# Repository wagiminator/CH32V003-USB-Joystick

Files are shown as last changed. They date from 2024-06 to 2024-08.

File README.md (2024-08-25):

# CH32V003 USB Joystick - Simple Joystick with USB Interface
The USB Joystick is a versatile device that combines the functionality of an analog joystick with the convenience of a USB interface. It is based on the affordable CH32V003 32-bit RISC-V microcontroller. One of the standout features of the USB Joystick is that it requires no driver installation, making it incredibly easy to use. The device acts as a USB Human Interface Device (HID), meaning that it can be recognized and utilized by most computers without the need for additional software. This makes the USB Joystick an ideal choice for a wide range of applications, not just as a game controller.

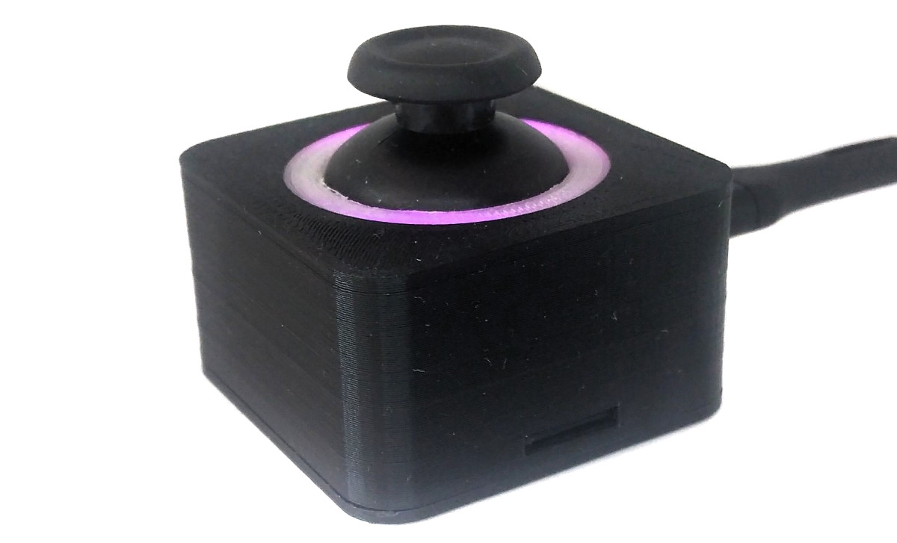
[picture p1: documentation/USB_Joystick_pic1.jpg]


# Hardware
## Schematic
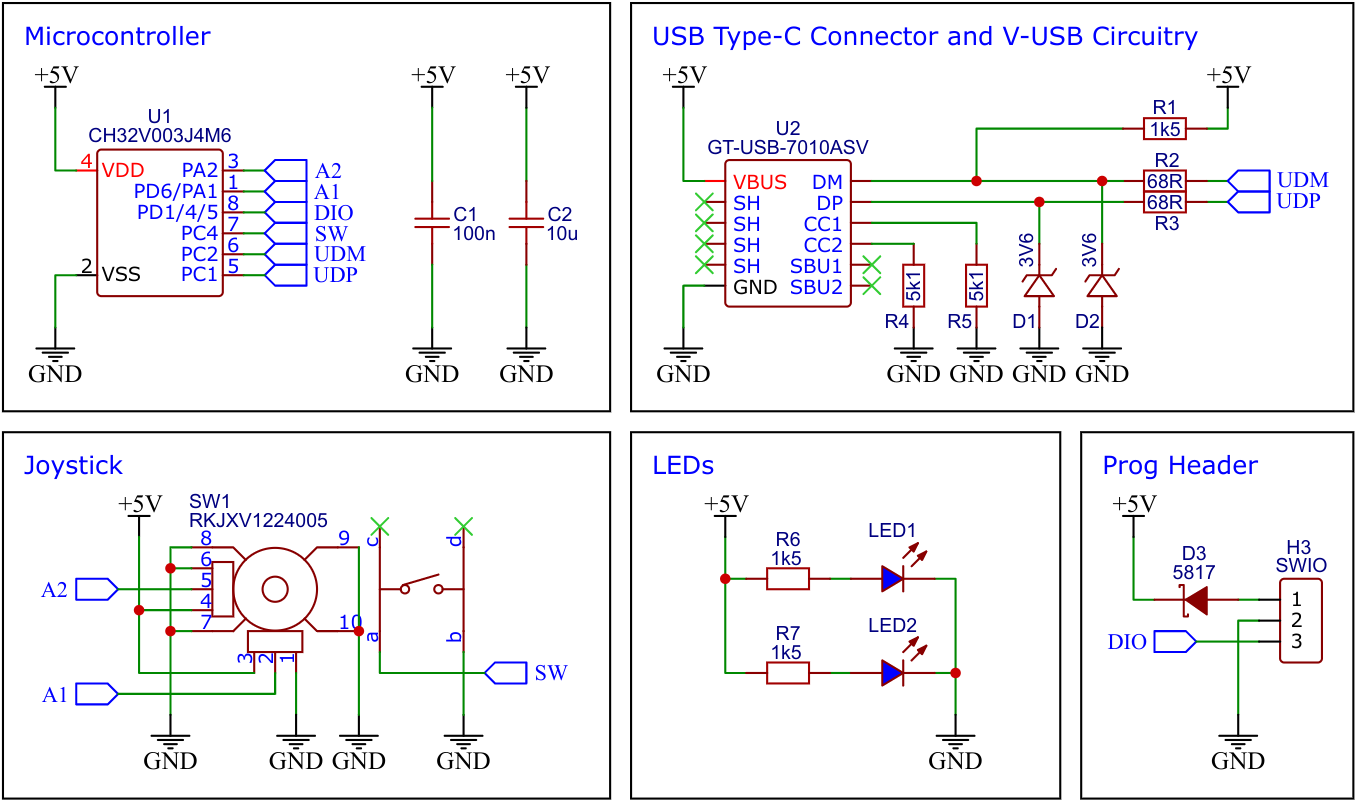
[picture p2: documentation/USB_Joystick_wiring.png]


## The CH32V003 Family of 32-bit RISC-V Microcontrollers
The CH32V003 series is a collection of industrial-grade general-purpose microcontrollers that utilize the QingKe RISC-V2A core design supporting the RV32EC instruction set. These microcontrollers are equipped with various features such as a 48MHz system main frequency, 16KB flash, 2KB SRAM, 2.7V - 5.5V supply voltage support, a single-wire serial debug interface, low power consumption, and an ultra-small package. Additionally, the CH32V003 series includes a built-in set of components including a DMA controller, a 10-bit ADC, op-amp comparators, multiple timers, and standard communication interfaces such as USART, I2C, and SPI.

## Building Instructions
1. Take the Gerber files (the *zip* file inside the *hardware* folder) and upload them to a PCB (printed circuit board) manufacturer of your choice (e.g., [JLCPCB](https://jlcpcb.com/)). They will use these files to create the circuit board for your device and send it to you.
2. Once you have the PCB, you can start soldering the components onto it. Use the BOM (bill of materials) and schematic as a guide to make sure everything is connected correctly. You can find the corresponding files in the *hardware* folder.
3. Upload the firmware by following the instructions in the next section (see below).
4. To create the case for your device, use the *stl* files in the *3dprint* folder with your 3D printer. Make sure to use transparent filament for the ring.
5. After printing, secure the PCB to the bottom of the case using four self-tapping M2x5mm screws.
6. Next, glue the ring from the bottom into the circular recess in the top of the case.
7. Finally, assemble the case. Your device is now ready to use!

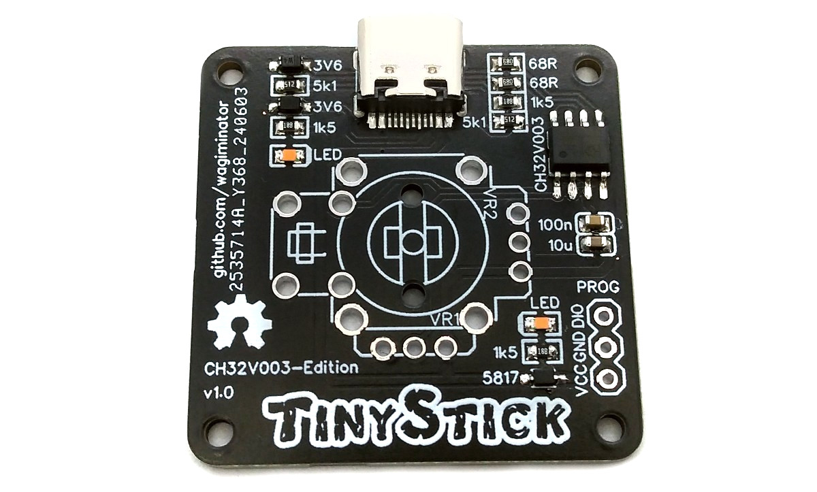
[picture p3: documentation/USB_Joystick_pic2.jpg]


# Software
## Software USB
Since the CH32V003 lacks a hardware USB peripheral, USB functionality is handled in software. Charles Lohr's excellent implementation, [RV003USB](https://github.com/cnlohr/rv003usb), is used for this. It emulates a USB low-speed device using pin-change interrupts and bit-banging, with assembly code for the low-level protocol and some C code for higher-level functionality.

## Firmware Versions
### Joystick
This firmware enables the USB Joystick to function as a one-button, two-axis game controller for your PC. The device is recognized as a USB HID game controller, ensuring seamless integration with your system. As a plug-and-play device, it should work immediately without the need for any driver installation, providing an effortless and user-friendly experience. Whether you're engaging in retro gaming or utilizing specialized software, this USB Joystick enhances your interaction with unparalleled simplicity and efficiency.

### Mousestick
This firmware is designed to transform the USB Joystick into a fully functional mouse controller, offering a unique and intuitive way to navigate your computer. By using the joystick, you can smoothly control the mouse pointer with precision. Additionally, the joystick button is conveniently mapped to the left mouse button, allowing for seamless clicking and selection. The device registers as a USB HID mouse on your computer, ensuring immediate functionality without the need for any driver installation. This plug-and-play capability makes it incredibly user-friendly, providing a hassle-free experience right out of the box.

## Programming and Debugging Device
To program the CH32V003 microcontroller, you will need a special programming device which utilizes the proprietary single-wire serial debug interface (SDI). The [WCH-LinkE](http://www.wch-ic.com/products/WCH-Link.html) (pay attention to the "E" in the name) is a suitable device for this purpose and can be purchased commercially for around $4. This debugging tool is not only compatible with the CH32V003 but also with other WCH RISC-V and ARM-based microcontrollers.



To use the WCH-LinkE on Linux, you need to grant access permissions beforehand by executing the following commands:
```
echo 'SUBSYSTEM=="usb", ATTR{idVendor}=="1a86", ATTR{idProduct}=="8010", MODE="666"' | sudo tee /etc/udev/rules.d/99-WCH-LinkE.rules
echo 'SUBSYSTEM=="usb", ATTR{idVendor}=="1a86", ATTR{idProduct}=="8012", MODE="666"' | sudo tee -a /etc/udev/rules.d/99-WCH-LinkE.rules
sudo udevadm control --reload-rules
```

On Windows, if you need to you can install the WinUSB driver over the WCH interface 1 using the [Zadig](https://zadig.akeo.ie/) tool.

To upload the firmware, you need to ensure that the USB Joystick is disconnected from USB. Then, you should make the following connections to the WCH-LinkE:

```
WCH-LinkE      USB-Joystick
+-------+      +------+
|  SWDIO| <--> |DIO   |
|    GND| ---> |GND   |
|    3V3| ---> |VCC   |
+-------+      +------+
```

If the blue LED on the WCH-LinkE remains illuminated once it is connected to the USB port, it means that the device is currently in ARM mode and must be switched to RISC-V mode initially. There are a few ways to accomplish this:
- You can utilize the Python command-line tool [rvprog](https://pypi.org/project/rvprog/) (with *-v* option).
- Alternatively, you can select "WCH-LinkRV" in the software provided by WCH, such as MounRiver Studio or WCH-LinkUtility.
- Another option is to hold down the ModeS button on the device while plugging it into the USB port.

More information can be found in the [WCH-Link User Manual](http://www.wch-ic.com/downloads/WCH-LinkUserManual_PDF.html).

## Compiling and Uploading Firmware using the Makefile
### Linux
Install the toolchain (GCC compiler, Python3, and rvprog):
```
sudo apt install build-essential libnewlib-dev gcc-riscv64-unknown-elf
sudo apt install python3 python3-pip
pip install rvprog
```

Disconnect the USB cable from the USB Joystick. Connect the USB Joystick via the 3-pin PROG header to the WCH-LinkE programming device. Open a terminal and navigate to the folder with the *makefile*. Run the following command to compile and upload:
```
make flash
```

### Other Operating Systems
Follow the instructions on [CNLohr's ch32v003fun page](https://github.com/cnlohr/ch32v003fun/wiki/Installation) to set up the toolchain on your respective operating system (for Windows, use WSL). Also, install [Python3](https://www.pythontutorial.net/getting-started/install-python/) and [rvprog](https://pypi.org/project/rvprog/). Compile and upload with "make flash". Note that I only have Debian-based Linux and have not tested it on other operating systems.

## Uploading pre-compiled Firmware Binary
WCH offers the free but closed-source software [WCH-LinkUtility](https://www.wch.cn/downloads/WCH-LinkUtility_ZIP.html) to upload the precompiled hex-file with Windows. Select the "WCH-LinkRV" mode in the software, open the *<firmware>.hex* file in the *bin* folder and upload it to the microcontroller.

Alternatively, there is an open-source tool called [minichlink](https://github.com/cnlohr/ch32v003fun/tree/master/minichlink) developed by Charles Lohr (CNLohr). It can be used with Windows, Linux and Mac.

If you have installed [Python3](https://www.pythontutorial.net/getting-started/install-python/) on your system, you can also use the platform-independent open-source command-line tool [rvprog](https://pypi.org/project/rvprog/) for uploading:
```
rvprog -f bin/<firmware>.bin
```

# References, Links and Notes
- [EasyEDA Design Files](https://oshwlab.com/wagiminator)
- [CNLohr: rv003usb](https://github.com/cnlohr/rv003usb)
- [MCU Templates](https://github.com/wagiminator/MCU-Templates)
- [MCU Flash Tools](https://github.com/wagiminator/MCU-Flash-Tools)
- [CH32V003 Datasheets](http://www.wch-ic.com/products/CH32V003.html)
- [CH32V003 USB Knob](https://github.com/wagiminator/CH32V003-USB-Knob)

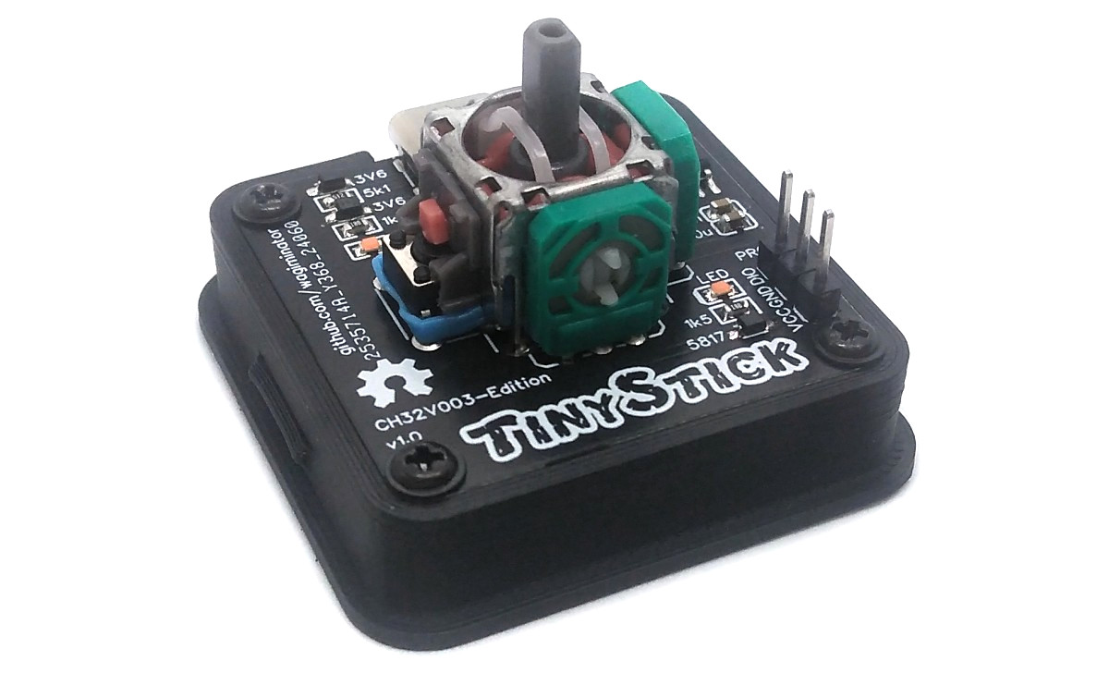
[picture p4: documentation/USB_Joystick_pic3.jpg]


# License


This work is licensed under Creative Commons Attribution-ShareAlike 3.0 Unported License. 
(http://creativecommons.org/licenses/by-sa/3.0/)

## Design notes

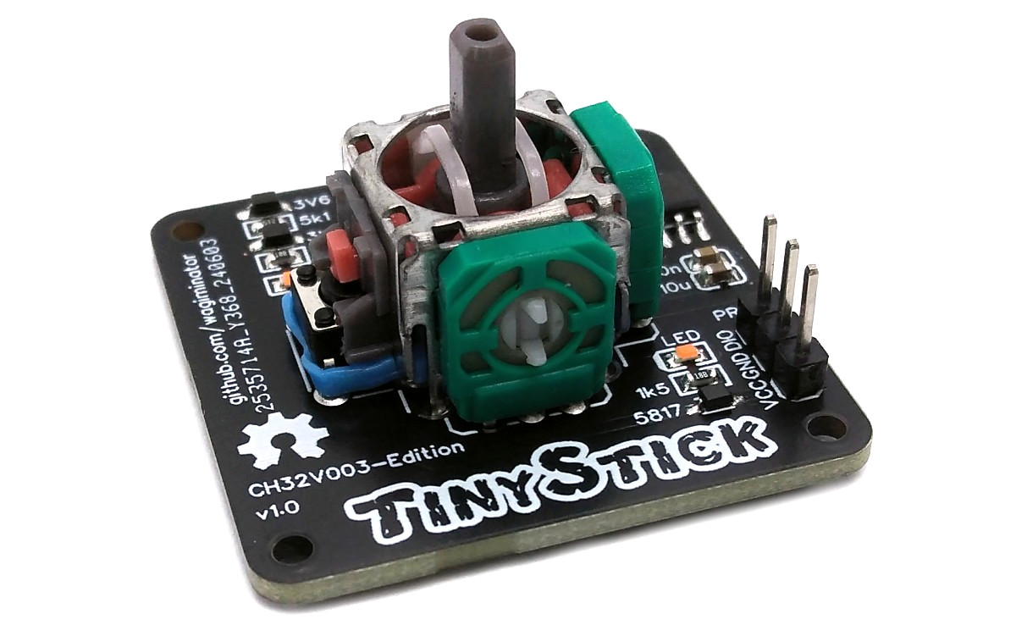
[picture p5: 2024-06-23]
documentation/USB_Joystick_pic4.jpg

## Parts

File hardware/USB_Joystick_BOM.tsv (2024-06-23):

ID | Name | Designator | Footprint | Quantity | Manufacturer Part | Manufacturer | Supplier | Supplier Part
1 | 100n | C1 | C_0603 | 1 | CC0603KRX7R9BB104 | YAGEO | LCSC | C14663
2 | 10u | C2 | C_0603 | 1 | CL10A106KP8NNNC | SAMSUNG | LCSC | C19702
3 | 3V6 | D1,D2 | ZENER_SOD_323 | 2 | BZT52C3V6S W4 | CBI(创基) | LCSC | C2886313
4 | 5817 | D3 | SCHOTTKY_SOD_323 | 1 | 1N5817WS | TWGMC | LCSC | C727114
5 | SWIO | H3 | 210S-3X1/2.54 | 1 | Header2.54mm 1*3P | BOOMELE | LCSC | C49257
6 | LED-0603-BLUE | LED1,LED2 | LED0603 | 2 | 19-217/BHC-ZL1M2RY/3T | EVERLIGHT | LCSC | C72041
7 | 1k5 | R1,R6,R7 | 0603 | 3 | 0603WAF1501T5E | UniOhm | LCSC | C22843
8 | 68R | R2,R3 | 0603 | 2 | 0603WAF680JT5E | UniOhm | LCSC | C27592
9 | 5k1 | R4,R5 | 0603 | 2 | 0603WAF5101T5E | UNI-ROYAL(厚声) | LCSC | C23186
10 | RKJXV1224005 | SW1 | SW-TH_RKJXV1224005 | 1 | RKJXV1224005 | ALPSALPINE(阿尔卑斯阿尔派) | LCSC | C146170
11 | CH32V003J4M6 | U1 | SOP-8_150MIL | 1 | CH32V003J4M6 | WCH(Jiangsu Qin Heng) | LCSC | C5346354
12 | GT-USB-7010ASV | U2 | USB-C-7010ASV-SX | 1 | GT-USB-7010ASV | G-Switch(品赞) | LCSC | C2988369

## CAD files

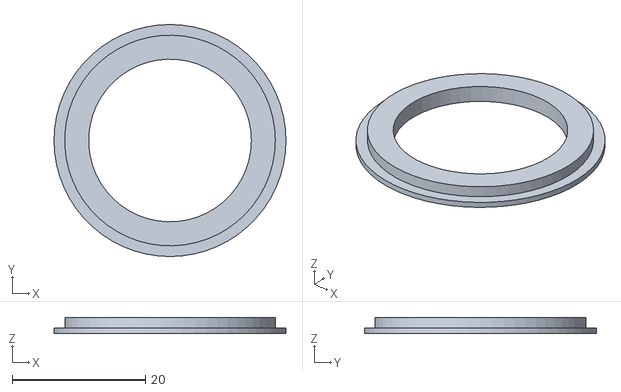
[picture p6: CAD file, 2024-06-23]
3dprint/USB_Joystick_case_ring.stl
34.8 x 34.8 x 2.40

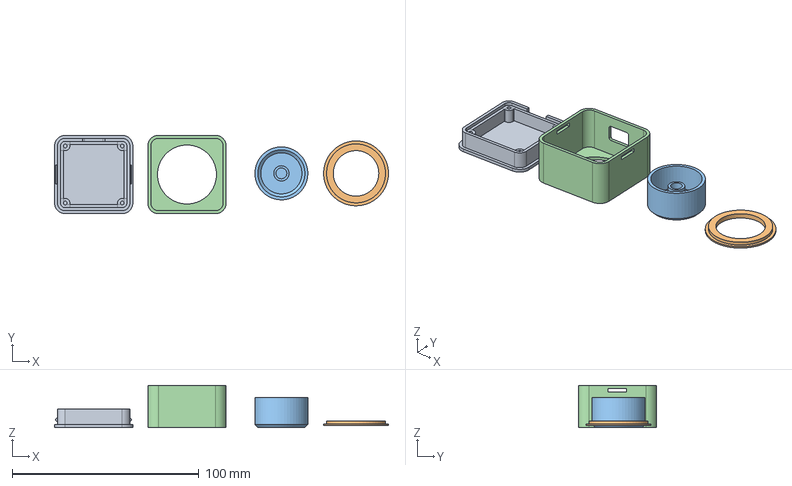
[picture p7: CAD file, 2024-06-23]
3dprint/USB_Joystick_case.fcstd
179.0 x 42.0 x 22.6 mm
Boden
LED-Ring
Knob
Deckel

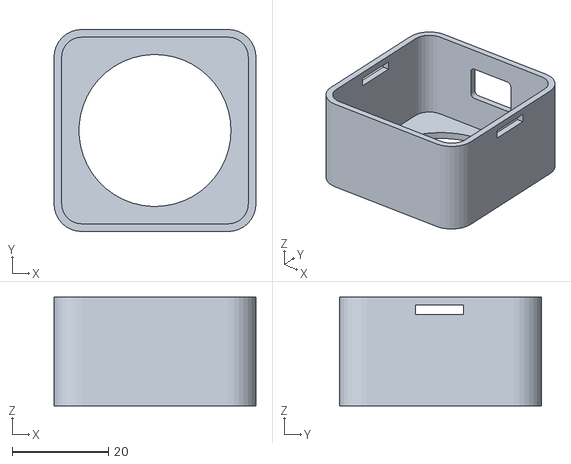
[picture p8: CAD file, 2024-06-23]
3dprint/USB_Joystick_case_top.stl
42.0 x 42.0 x 22.6

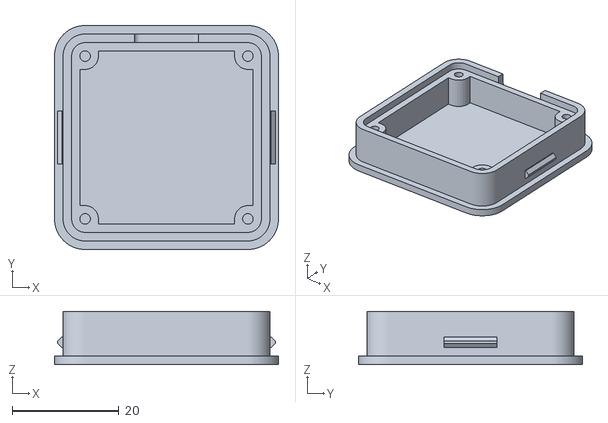
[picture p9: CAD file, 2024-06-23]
3dprint/USB_Joystick_case_bottom.stl
42.0 x 42.0 x 10.0

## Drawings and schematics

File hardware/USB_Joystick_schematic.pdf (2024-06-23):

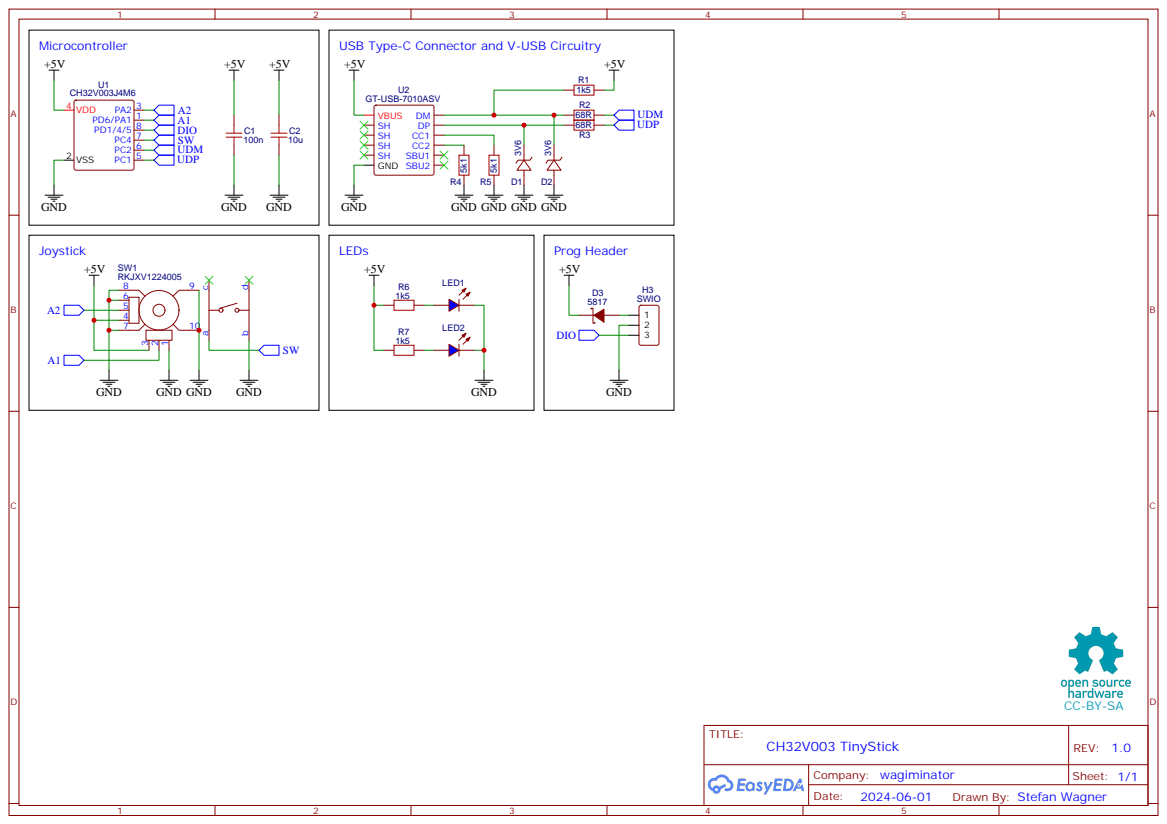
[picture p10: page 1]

USB Type-C Connector and V-USB Circuitry

GND GND GND ³V⁶

Drawn By: Stefan Wagner

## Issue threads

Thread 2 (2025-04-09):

Tinystick with ginfull hall effect drop-in replacement and default joystick firmware.

jonpeate, 2025-04-09:
Hi, I have been playing around with a lot of different joystick designs for a friend with muscular atrophy, he requires low tension joysticks and his current setup does the trick but there are some things to improve.

The setup is a xbox adaptive controller with a hall effect joystick plugged into its left side USB port currently used as both the mouse pointer and left joystick with software switching, and a lot of little 3.5mm jack joysticks made by a company I will not mention just yet, but I have pulled apart a lot of defective units that all seem have the same sticking issue, I think its to do with the replacement spring that lowers the tension, it bends out of shape pretty easily. The 2-axis joysticks most of them use seems to be alps alpine 2, and despite being literally a shell with a joystick on a PCB inside wired up to a 3.5mm cable, each unit seems to cost about ~$200 AUD minus shipping.

Due to some issues I've been having with ginfull drop in replacement hall effect joysticks soldered into the 3.5mm jack device (permanently stuck in up position), I decided to look further and found this project, the same ginfull joystick with 0.3mm/10mm/5mm (wire dia/length/outer dia) spring that went haywire works fairly ok on the TinyStick even with the provided pre-compiled joystick-mode firmware.
I have played GTA VCS on pcsx2 with it plugged directly into USB, and GTA SA definitive while in the xbox adaptive controller. I have also used some online gamepad tester and it behaves basically the same whether direct or in the adaptive controller, its not quite there yet though.
Right now axis 0 has a max left value of -0.77953 while max right is 1.00. Axis 1 has a max up of -0.94488 and max down of 1.00. Also has small deadzones in each corner.

I am hoping to get this fully working on the Tinystick but my electronics and programming skills are fairly limited, will see how it goes. Thinking of trying with the original spring to see how it behaves, and installing another one of a different size, then looking at the source code and learning how I could change it in the correct way.

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

wagiminator, 2025-05-02:
Thanks a lot for the feedback. This project was more of a little experiment rather than a serious application. There's definitely some room for improvement in calibration on the software side. However, I'm not sure whether the cheap joystick can ultimately be used with real precision.

jonpeate, 2025-05-23:
Thanks for the reply, I'm trying out an Arduino pro micro clone due to the large amount of support, pre-existing calibration software and commercial use in accessibility products such as the celtic magic dangle. Still have 5 assembled tinysticks which will end up being used in the future, just with the ALPS joystick listed in the BOM instead, I will probably give some to those in my local computer club for those who want a project involving coding, and for use in stuff like pi-powered arcades. Ill be glad to share any progress that might be made some day.

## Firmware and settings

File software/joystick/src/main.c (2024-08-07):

// ===================================================================================
// Project:   USB Stick for CH32V003 - Game Controller (Joystick)
// Version:   v1.0
// Year:      2024
// Author:    Stefan Wagner
// Github:    https://github.com/wagiminator
// EasyEDA:   https://easyeda.com/wagiminator
// License:   http://creativecommons.org/licenses/by-sa/3.0/
// ===================================================================================
//
// Description:
// ------------
// Standard one-button two-axis HID game controller.
//
// References:
// -----------
// - CNLohr ch32v003fun: https://github.com/cnlohr/ch32v003fun
// - CNLohr rv003usb:    https://github.com/cnlohr/rv003usb
// - WCH Nanjing Qinheng Microelectronics: http://wch.cn
//
// Compilation Instructions:
// -------------------------
// - Make sure GCC toolchain (gcc-riscv64-unknown-elf, newlib) and Python3 with rvprog
//   are installed. In addition, Linux requires access rights to WCH-LinkE programmer.
// - Connect the WCH-LinkE programmer to the MCU board.
// - Run 'make flash'.
//
// Operating Instructions:
// -----------------------
// - Connect the board to your PC via USB while the joystick is in its neutral 
//   position (for calibration at start-up).
// - The device should be detected by your operating system as a standard HID game
//   controller.
// - Use the USB Stick as a standard one-button two-axis game controller.


// ===================================================================================
// Libraries, Definitions and Macros
// ===================================================================================
#include <config.h>                               // user configurations
#include <system.h>                               // system functions
#include <gpio.h>                                 // GPIO functions
#include <usb_joystick.h>                         // USB HID joystick functions

// ===================================================================================
// Main Function
// ===================================================================================
int main(void) {
  // Variables
  uint16_t JOY_X_middle, JOY_Y_middle;            // joystick neutral position values
  int16_t  JOY_X_pos, JOY_Y_pos;                  // current joystick position values

  // Setup
  PIN_input_AN(PIN_JOY_X);                        // set pins
  PIN_input_AN(PIN_JOY_Y);
  PIN_input_PU(PIN_JOY_SW);

  DLY_ms(1);                                      // wait a bit for USB
  JOY_init();                                     // init USB HID game controller
  ADC_init();                                     // init ADC
  ADC_slow();                                     // slow ADC sampling

  ADC_input(PIN_JOY_X);                           // set joystick x-poti as ADC input
  JOY_X_middle = ADC_read();                      // read neutral value
  ADC_input(PIN_JOY_Y);                           // set joystick y-poti as ADC input
  JOY_Y_middle = ADC_read();                      // read neutral value

  // Loop
  while(1) {
    // Set joystick button
    PIN_read(PIN_JOY_SW) ? JOY_release(1) : JOY_press(1);

    // Set joystick axis position
    ADC_input(PIN_JOY_X);
    JOY_X_pos = ((int16_t)ADC_read() - JOY_X_middle) >> 2;
    if(JOY_X_pos >  127) JOY_X_pos =  127;
    if(JOY_X_pos < -127) JOY_X_pos = -127;

    ADC_input(PIN_JOY_Y);
    JOY_Y_pos = ((int16_t)ADC_read() - JOY_Y_middle) >> 2;
    if(JOY_Y_pos >  127) JOY_Y_pos =  127;
    if(JOY_Y_pos < -127) JOY_Y_pos = -127;

    JOY_stick(JOY_X_pos, JOY_Y_pos);
  }
}

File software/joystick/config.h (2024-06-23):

// ===================================================================================
// User Configurations
// ===================================================================================

#pragma once

// Joystick pin definitions
#define PIN_JOY_X           PA1       // pin connected to joystick poti x-direction
#define PIN_JOY_Y           PA2       // pin connected to joystick poti y-direction
#define PIN_JOY_SW          PC4       // pin connected to joystick switch

// USB pin definitions
#define USB_PORT            C         // [A,C,D] GPIO Port to use with D+ and D-
#define USB_PIN_DP          1         // [0-4] GPIO Number for USB D+ Pin
#define USB_PIN_DM          2         // [0-4] GPIO Number for USB D- Pin

// USB configuration descriptor
#define USB_MAX_POWER_mA    50        // max power in mA 

// USB device descriptor
#define USB_VENDOR_ID       0x1209    // VID
#define USB_PRODUCT_ID      0xc003    // PID
#define USB_DEVICE_VERSION  0x0100    // v1.0 (BCD-format)
#define USB_LANGUAGE        0x0409    // US English

// USB descriptor strings
#define MANUF_STR           "wagiminator"
#define PROD_STR            "TinyJoyStick"
#define SERIAL_STR          "CH32V003HID"
